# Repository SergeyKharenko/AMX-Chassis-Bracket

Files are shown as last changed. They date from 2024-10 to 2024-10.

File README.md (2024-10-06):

# AMX Chassis Bracket
<div align="center">
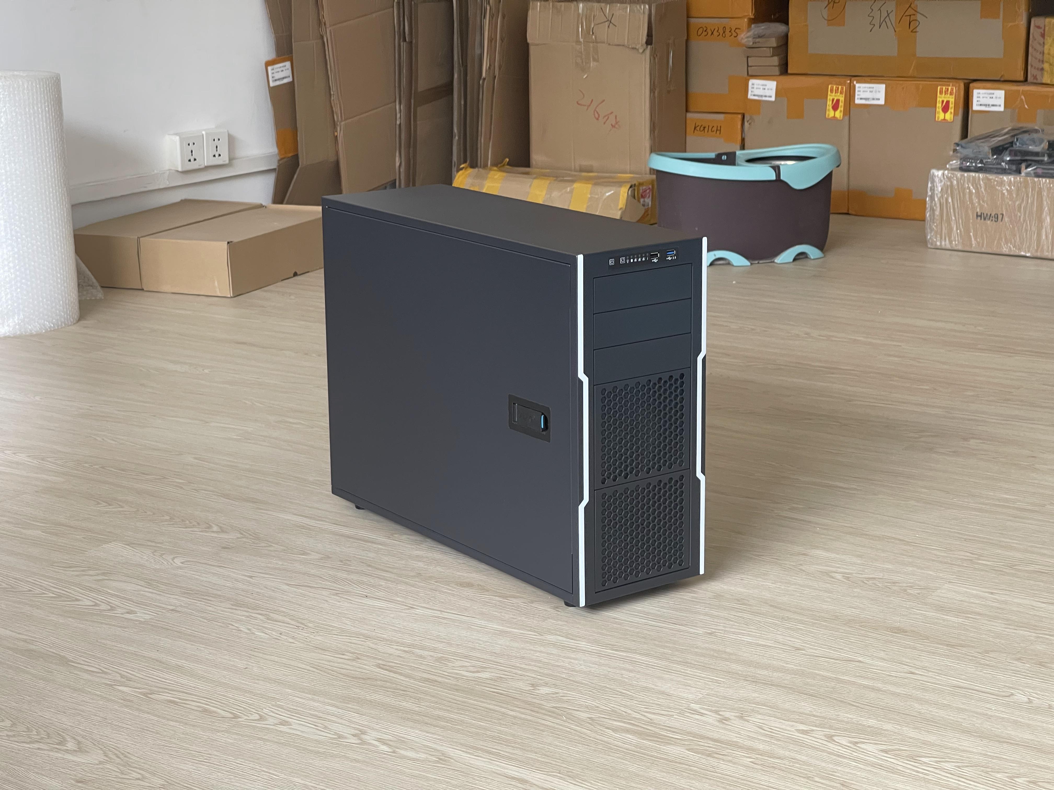
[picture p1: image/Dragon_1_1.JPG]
    
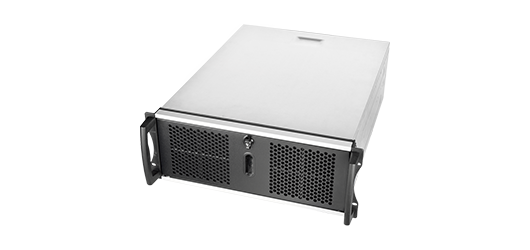
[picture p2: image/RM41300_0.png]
    
</div>
<div align="center">
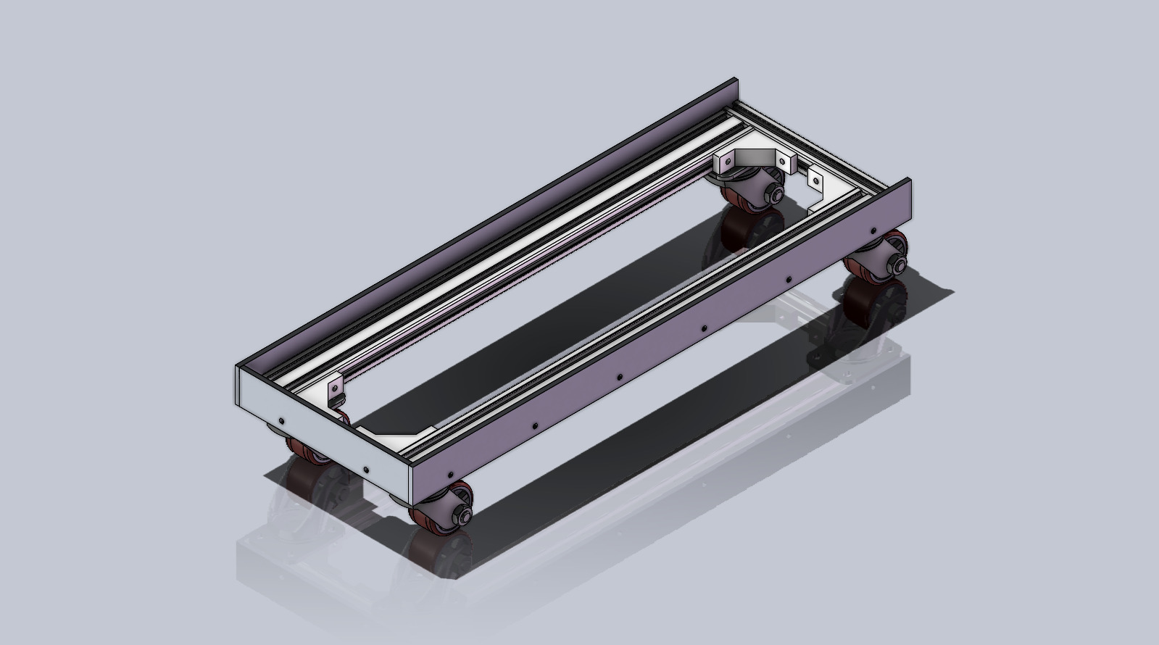
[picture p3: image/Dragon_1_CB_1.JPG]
    
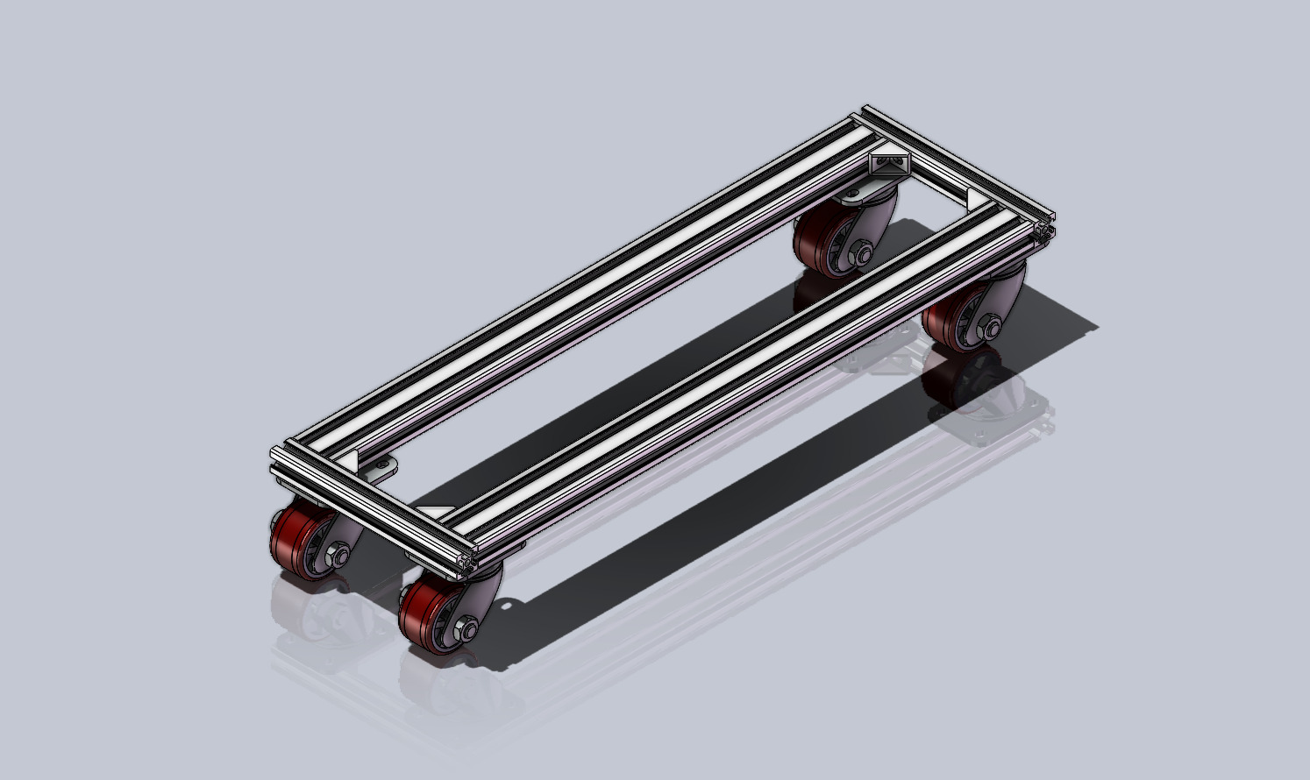
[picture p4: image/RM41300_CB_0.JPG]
    
</div>

## Introduction

This project starts with a PC building in June 2022, I found it is difficult to moving my heavy chassis. Besides, existing chassis brackets on Taobao is either unstable or too expensive(over 200 yuan). Therefore I decided to build the bracket by myself. 

The project aims to provide a fully open source solution of the chassis bracket with advantages below:

- **Fit**  Tailor-made according to the actual size of the chassis to meet your various obsessive-compulsive disorders.
- **Stable**  Aluminum Profile(AP) can support any heavy chassis. Will it shake? IMPOSSIBLE!!! It is much better than any one you can buy online.
- **Cool**  Hollowing out at the bottom is beneficial for heat dissipation of some chassis with vents at the bottom.
- **Quiet** Rubber casters can absorb vibration well.
- **Customizable** All accessories are customizable, you can choose freely according to your needs.

Finished parts(casters) and standard parts(AP) are widely used to reduce costs. However, **it might NOT be so cheap** because the cost of small parts such as screws is also considerable. According to my previous cases, **the total cost range is about 120-180 yuan.** In short, this solution might not be suitable for users who are **extremely cost-sensitive**.

## Compatible Chassis
Currently, I have implemented the following chassis brackets:
- [Dragon 1](chassis/Dragon_1/README.md)
- [RM41300](chassis/RM41300/README.md)

If you have new ideas, welcome to raise an issue~

## Before You Start

### Default Units

**This project uses millimeters(mm) as the unit of length by default!!!** 
Special cases will be specifically pointed out.

### How to use T-Nut
[Bilibili(Chinese)](https://player.bilibili.com/player.html?isOutside=true&aid=917693577&bvid=BV1tu4y1Y7eb&cid=1313380385&p=1),
[Youtube(English)](https://www.youtube.com/watch?v=_kZTA5S2jWY)

### How and Why to use Washer
[Bilibili(Chinese)](https://www.bilibili.com/video/BV1Qz4y1T7m6/?share_source=copy_web&vd_source=c79616b3b42ebfb1c3a4223d9ffdf564),
[Youtube(English)](https://www.youtube.com/watch?v=lbIHMyxHkds)

### Recommended Assembly
<div align="center">
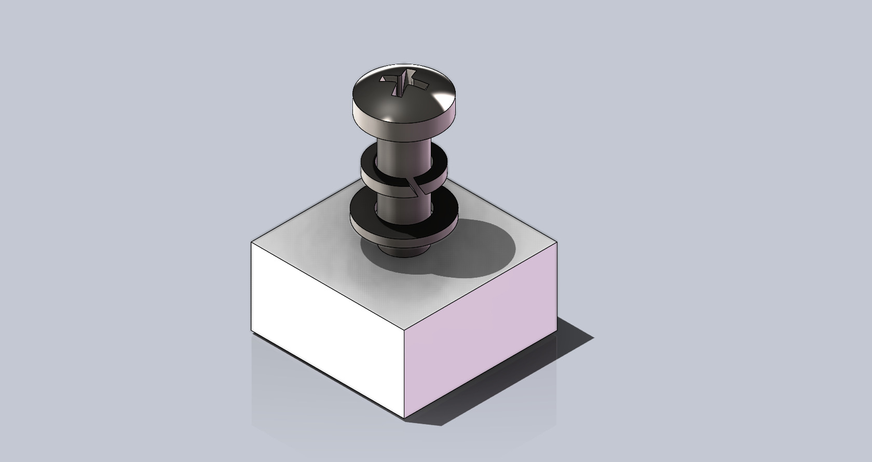
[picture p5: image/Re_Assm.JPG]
    
</div>

From top to bottom in the fig are **screws, spring washers, flat washers, and part to be installed**.

### Standard Part
#### Aluminum Profile
Aluminum profiles are versatile components widely used in various industries, including construction, automotive, and manufacturing. These profiles are typically created through an extrusion process, where heated aluminum alloy is forced through a die to achieve specific shapes and sizes.

T-slot aluminum(TSA) is a type of extruded aluminum profile that features a T-shaped slot running along its length. This design allows for easy and flexible connection of different aluminum profiles using a variety of connectors, fasteners, and accessories. So this project use it as the main support component. 

<div align="center">
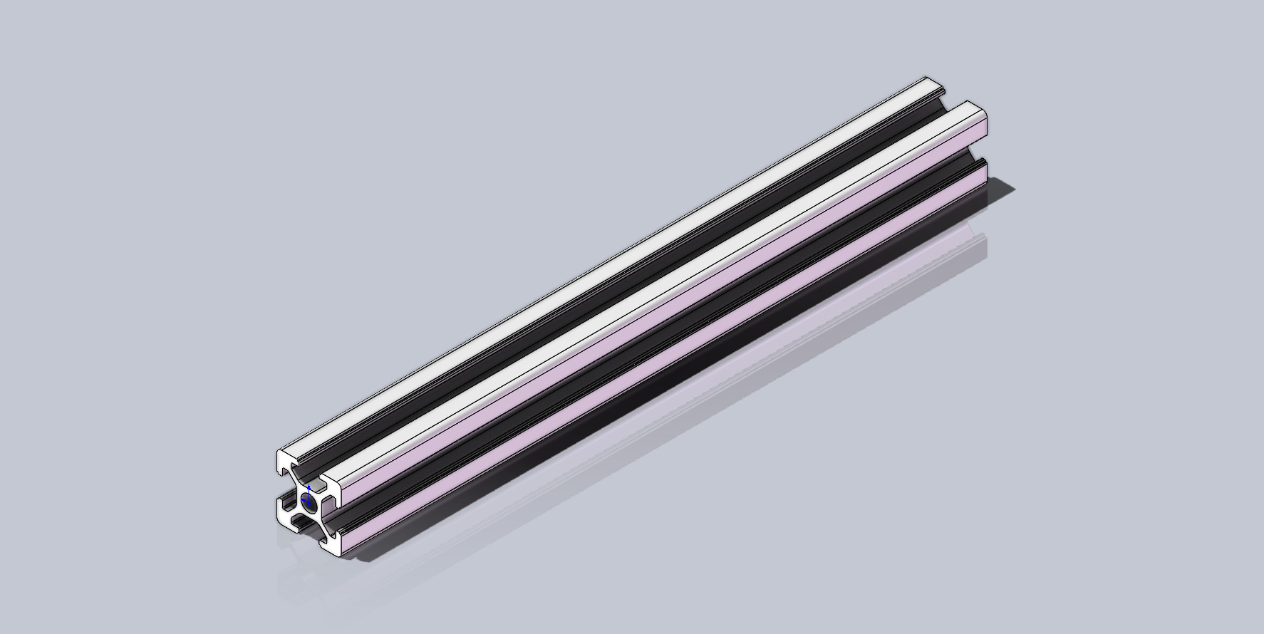
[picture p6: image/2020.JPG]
    
</div>

Model name of the TSA is based on the cross-sectional dimensions. E.g. the cross-sectional dimension of 20 mm in both width and height is named 2020. Common models are 1515, 2020, 2040, 2060, 3030...

**This project mainly uses the Model 2020 and 2040 to get a good balance between cost and stiffness.**

In addition, there are variants of single-sided or even multi-sided closure of TSA:
<div align="center">
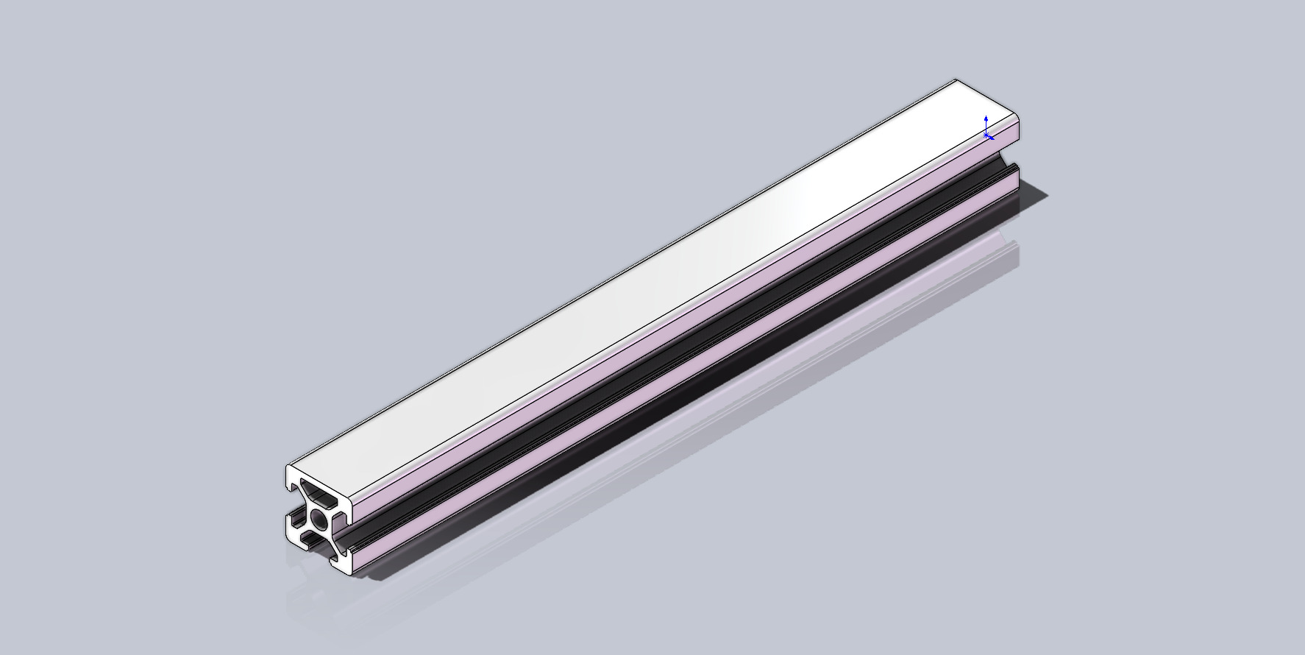
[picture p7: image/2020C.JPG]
    
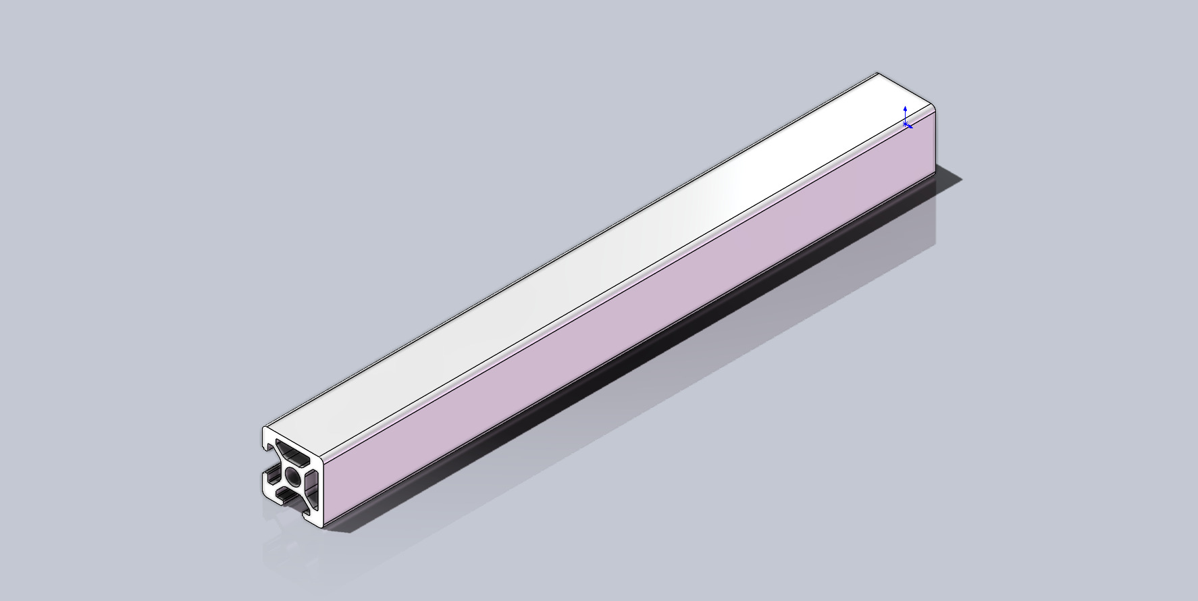
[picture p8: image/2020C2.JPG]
    
</div>

#### Corner Connector

Corner connector is one of the most common fastener used for TSA. It has a variety of sizes, corresponding to different models of TSA.

<div align="center">
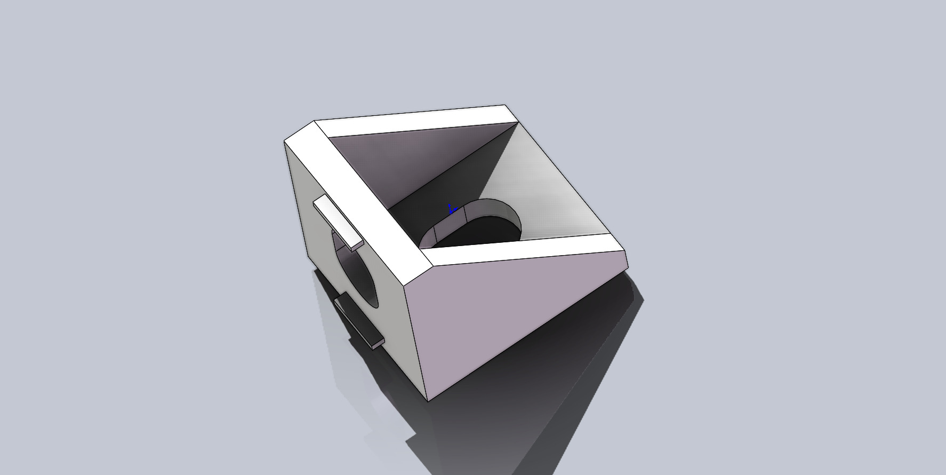
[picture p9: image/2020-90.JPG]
    
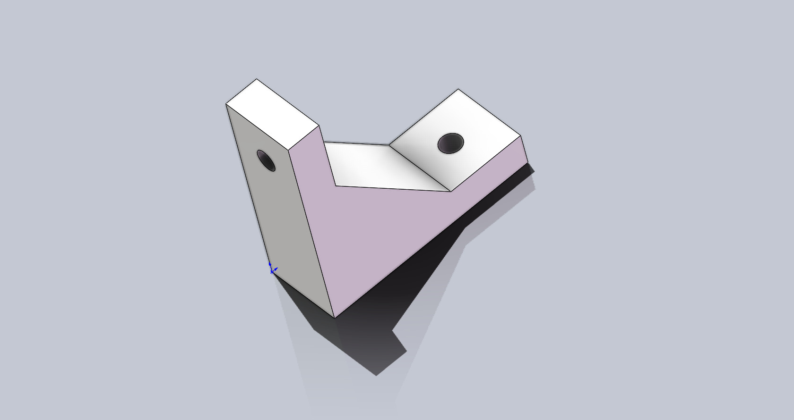
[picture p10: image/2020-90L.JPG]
    
</div>

The left is the standard corner connector. It can be purchased in any store that specializes in TSA.
The right has better structural strength(also a little more expensive). It is provided by the store where I bought. I believe other store also have similar part. The size might not be the same. 

**You can choose flexibly according to the actual situation.**

Fig below is an example of its' usage:
<div align="center">
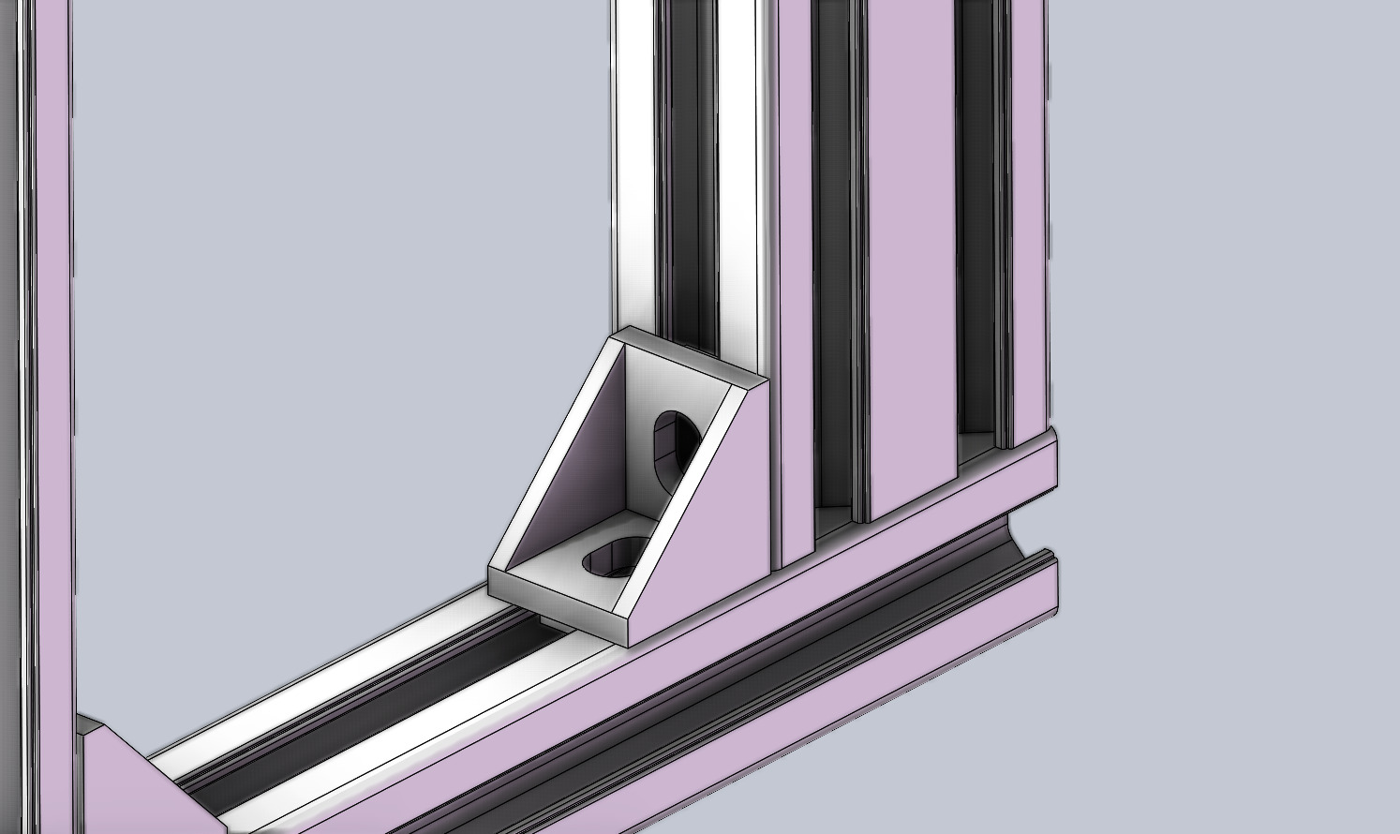
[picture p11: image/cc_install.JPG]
    
</div>

### Caster

The caster is the core to the free movement of the chassis. Reliable castor is equipped with a variety of bearings to support pressure while meeting the need for smooth movement. Of course, this also leads to the fact that this part may be a little expensive (around 20-30 yuan per set).

<div align="center">
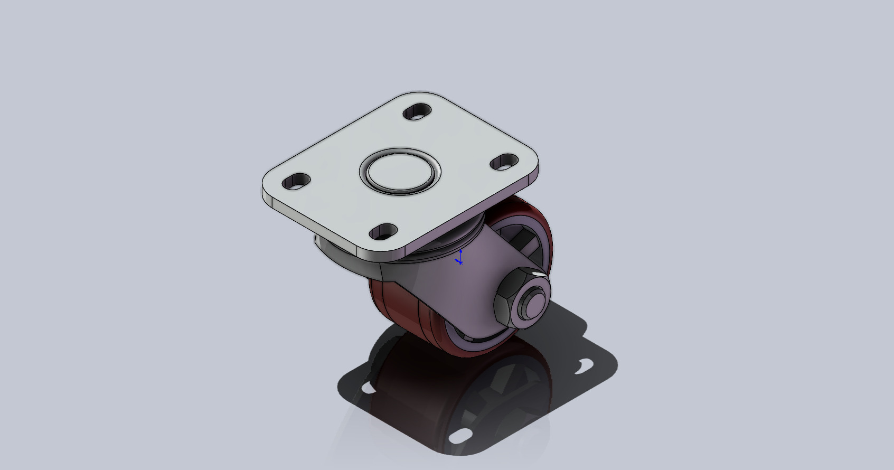
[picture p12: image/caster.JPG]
    
</div>

According to the size of the wheel diameter, the common casters are 1-inch, 1.25-inch, 1.5-inch, 2-inch, etc... 

**It is important to note that casters that are too small have a very limited load capacity, and casters that are too large will cause the center of the chassis gravity to be too high and cause instability**

Based on previous experience, **it is recommended to use casters of 1.5-inch**.

## Design and Review
### Prerequisites
- Dassault Systèmes' SOLIDWORKS 2024 and higer

### Folder Structures
```
|-- AMX Classis Bracket
            |
            |---- chassis Parts and assemblies of brackets for different chassis
            |       |
            |       |---- share Shared parts(corner connector, caster...)
            |       |
            |       |---- Dragon_1 
            |       |
            |       |---- RM41300
            |       :
            |       :
            |       |---- Other Classis
            |
            |---- drawing Machining drawings
            |
            |---- image Images used in README
```

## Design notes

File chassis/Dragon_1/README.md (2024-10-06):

# Dragon 1
<div align="center">
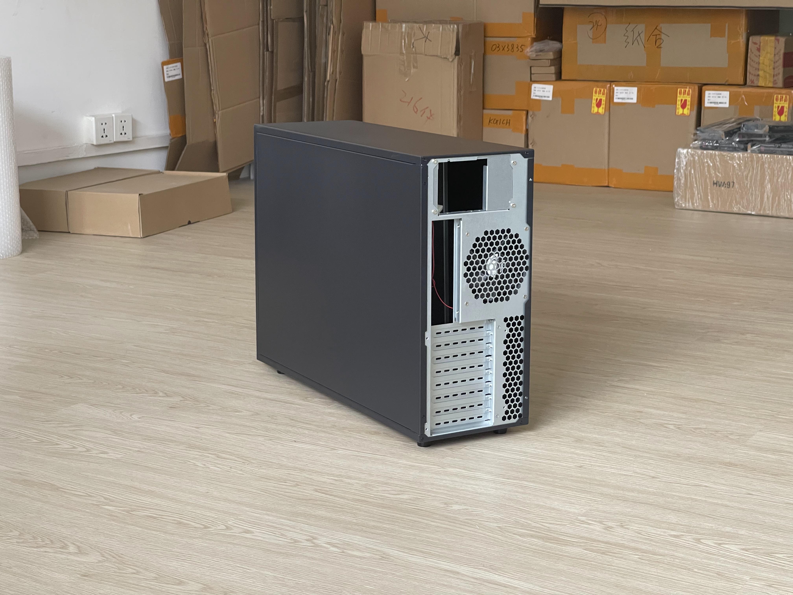
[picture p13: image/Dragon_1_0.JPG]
    
    
</div>
<div align="center">
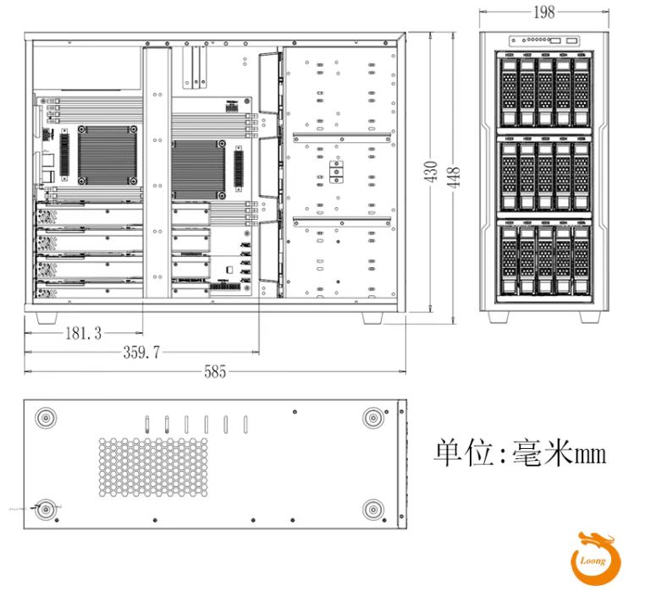
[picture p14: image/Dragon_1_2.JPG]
    
</div>

## Chassis Bracket
<div align="center">
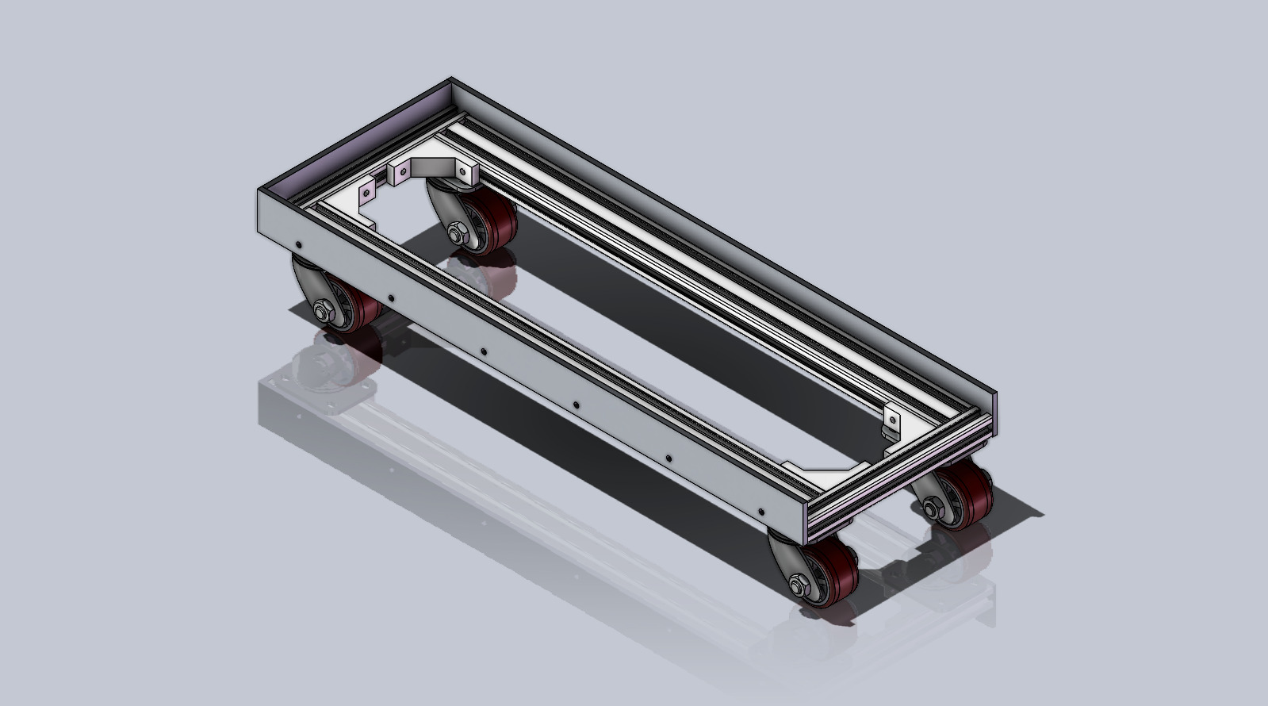
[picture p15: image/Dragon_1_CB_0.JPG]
    
    
</div>

## BOM

| Name | Model | Spec | Drawing | Quantity | Price(yuan) | Note |
|:---:|:---:|:---:|:---:|:---:|:---:|:---:|
| TSA | 2020 | Length: 200 | | 2 | 5.54 |  Recommend single-sided closure |
| | 2040 | Length: 545 | | 2 | 25.51 |  Recommend single-sided closure on 40 side |
| Corner Connector | Compatible to Model 20 TSA | | | 4 | 9.8 | |
| Aluminum Panel | Thick: 5, Width: 40 | Length: 200 | [c0](../../drawing/cover5X40X200.pdf) | 1 | 3.17 | Send drawing to the manufacturer*  |
| | | Length: 590 | [c1](../../drawing/cover5X40X590.pdf) | 2 | 18.71 | Send drawing to the manufacturer |
| Caster | 1.5-inch | | | 1 set | 30 |  1 set include 4 casters |
| Washer | Spring Washer | M5 | | 20 | 6.8 | |
| | Flat Washer | 5\*12\*1.0  | | 20 | 6 | |
| Hexagon Socket Screw | Round Head | M5*8 | | 20 | 5 | |
| | Flat Head Chamfered | M5*10 | | 14 | 5.85 |  For fastening side panels |
| T-Nut | Compatible to Model 20 TSA | M5 | | 34 | 3.4 | |
| Rubber Feet** | D: 40, Thick: 8 | | | 4 | 8 | |
| Miscellaneous*** | | | | | 35 | |
| Total | | | | | 168 | |

*note: Holes need to be drilled, so the drawing must be sent to the manufacturer!

**note: As shown in the fig below:

<div align="center">
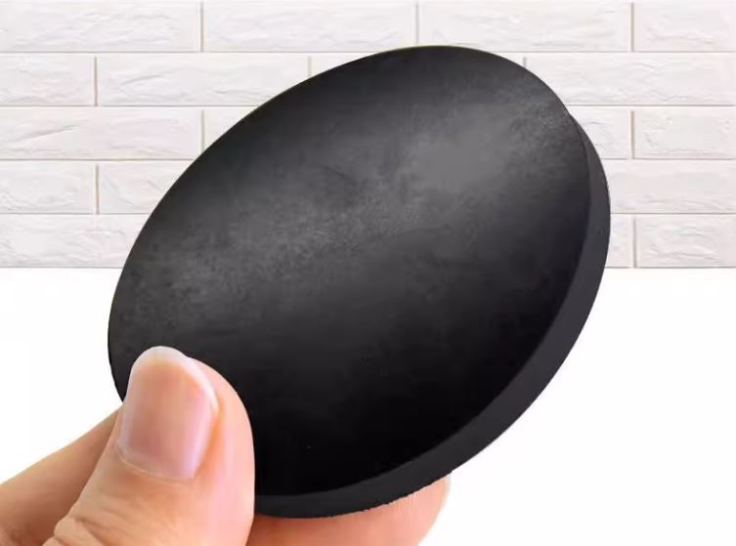
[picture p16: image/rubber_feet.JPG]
    
</div>

***note: Include machining, freight, etc.

## Prerequisites

- Hexagonal Wrench
- Small File
- Phillips Screwdriver

## How to Install

<div align="center">
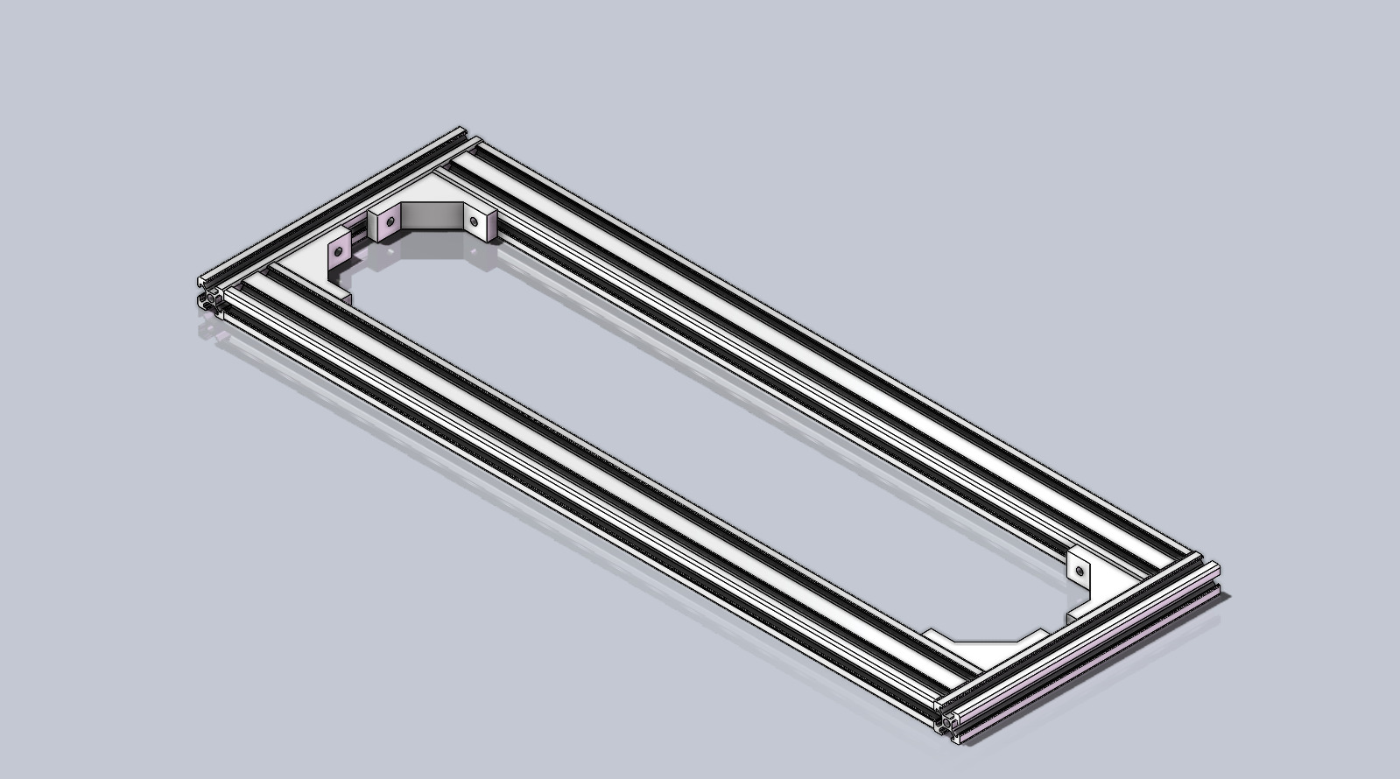
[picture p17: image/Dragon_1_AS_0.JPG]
    
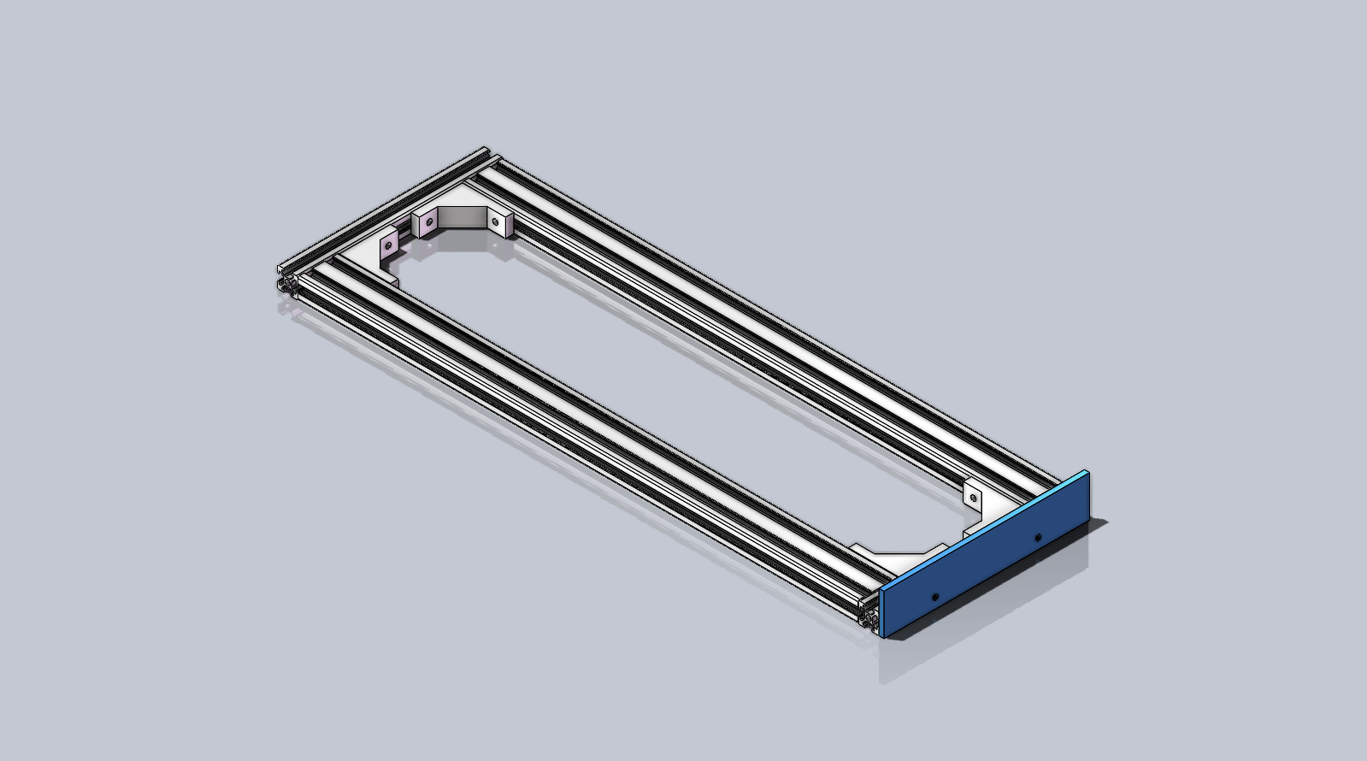
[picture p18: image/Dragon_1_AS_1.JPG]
    
</div>
<div align="center">
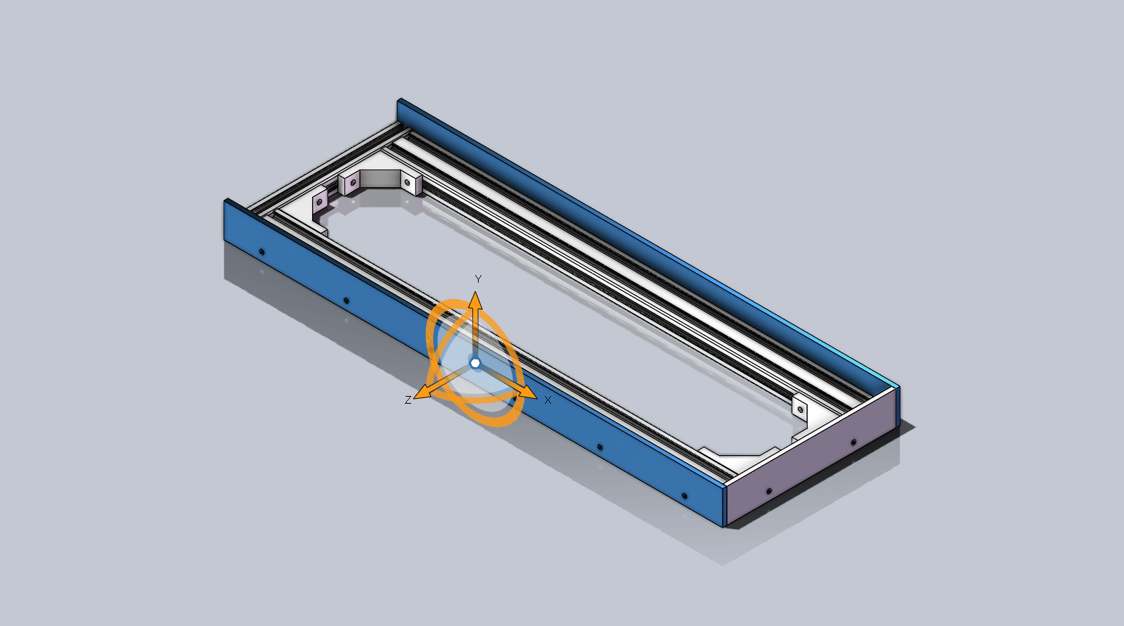
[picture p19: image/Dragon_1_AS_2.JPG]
    
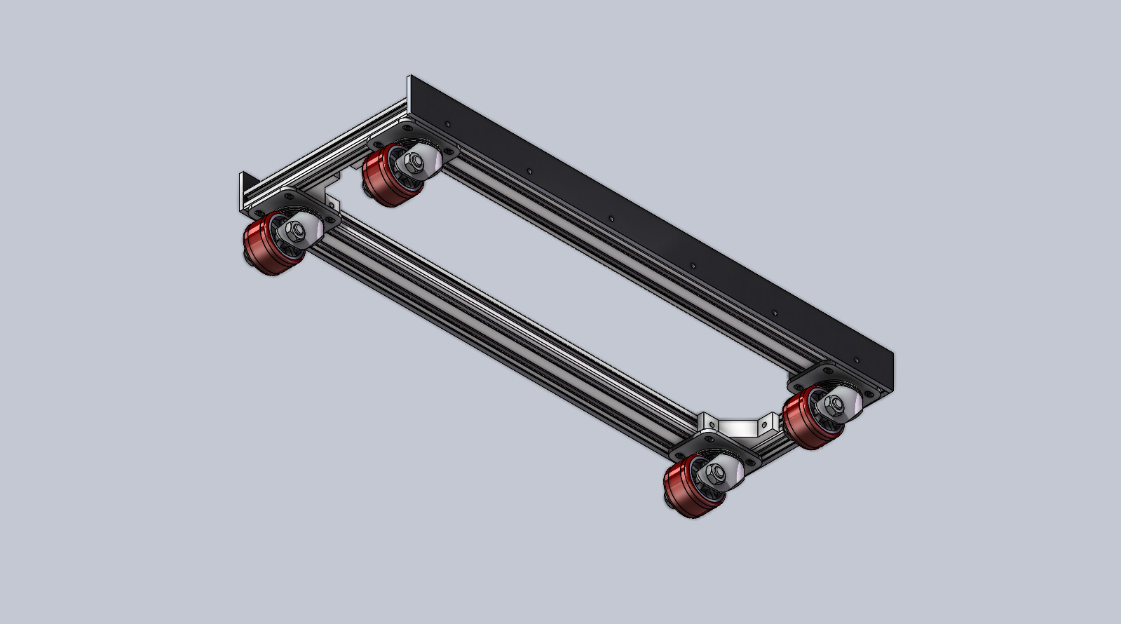
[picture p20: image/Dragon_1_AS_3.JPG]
    
</div>
<div align="center">
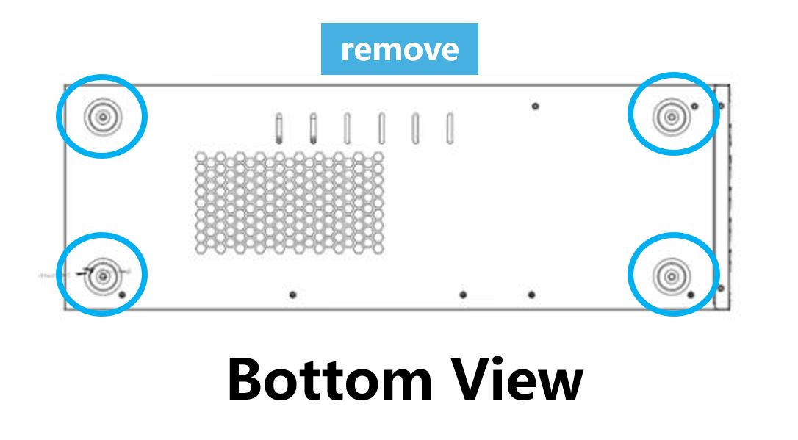
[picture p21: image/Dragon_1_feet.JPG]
    
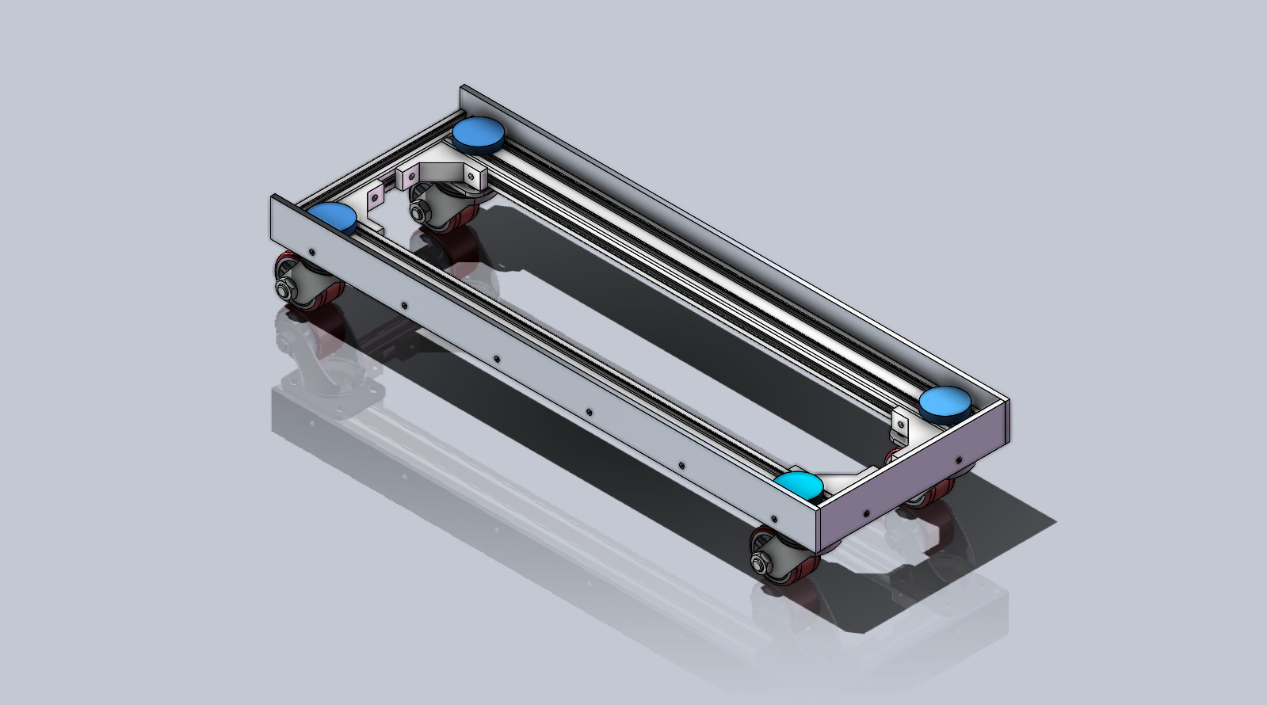
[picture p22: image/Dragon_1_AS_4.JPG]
    
</div>

1. Connecting TSA using corner connector. Pay attention to the assembly order! It is recommended to assemble on a flat surface (such as the ground)
2. Install the rear side panel*.
3. Install the left and right side panels. They can wrap the rear side panel.
4. Install casters.
5. Remove the original feet installed under the chassis.
6. Place the rubber feet on the bracket.
7. Place the chassis on the bracket.

*note: When installing the side panels, washers can be omitted for aesthetic reasons, so that the screw heads can fit perfectly with the side panels.

## Caution

The cut edges of the side panels and cornet connector may be sharp, so it is recommended to use a file for chamfering.

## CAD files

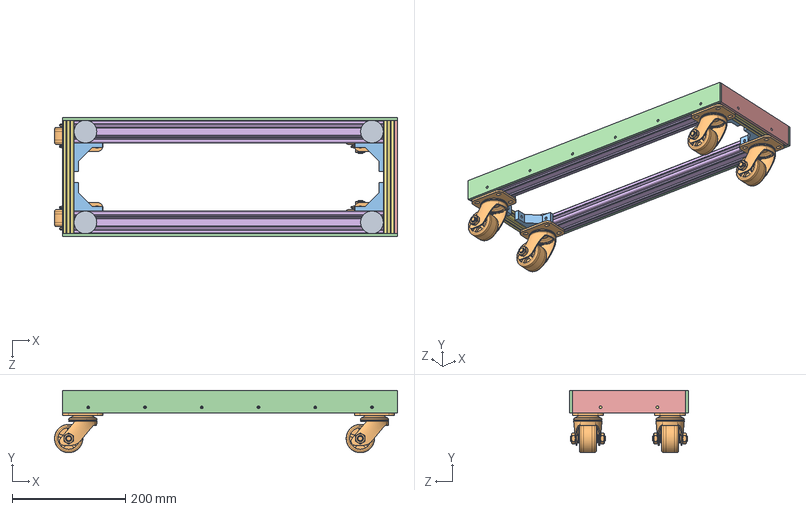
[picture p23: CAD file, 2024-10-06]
chassis/Dragon_1/Dragon_1.SLDASM
604.5 x 110.0 x 210.0 mm
2020X200 x 2
2040X545 x 2
cover5X40X200
cover5X40X590 x 2
2020-90L x 4
caster x 4
rubber_feet_8x40 x 4

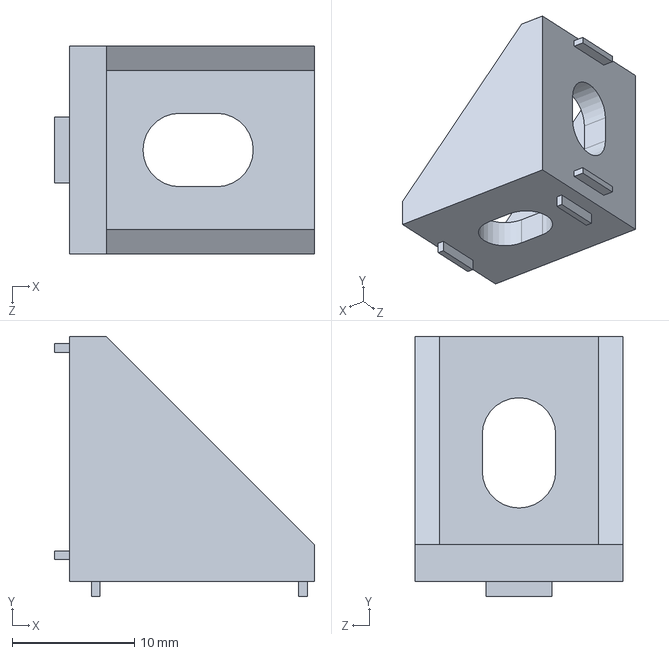
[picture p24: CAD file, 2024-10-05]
chassis/share/2020-90.SLDPRT
21.2 x 21.2 x 17.0 mm

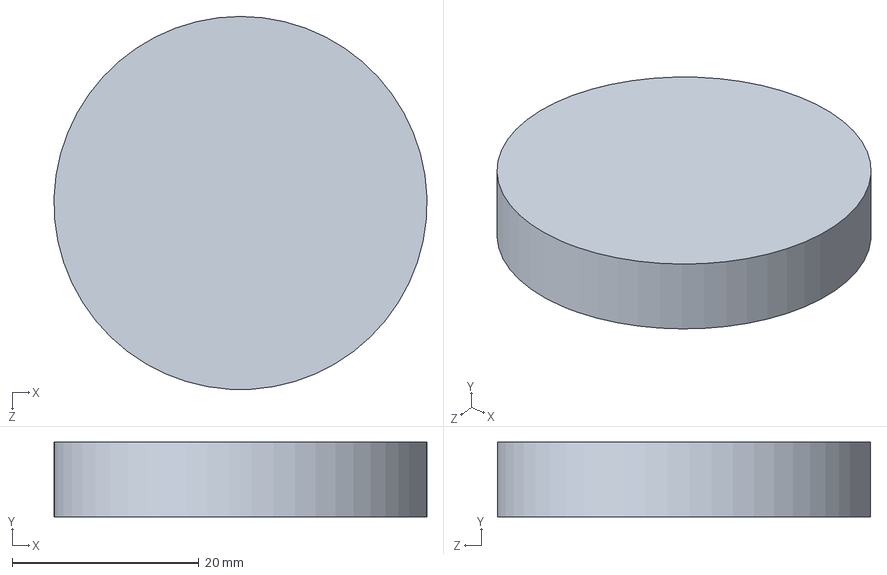
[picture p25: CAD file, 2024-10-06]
chassis/Dragon_1/rubber_feet_8x40.SLDPRT
40.0 x 8.00 x 40.0 mm

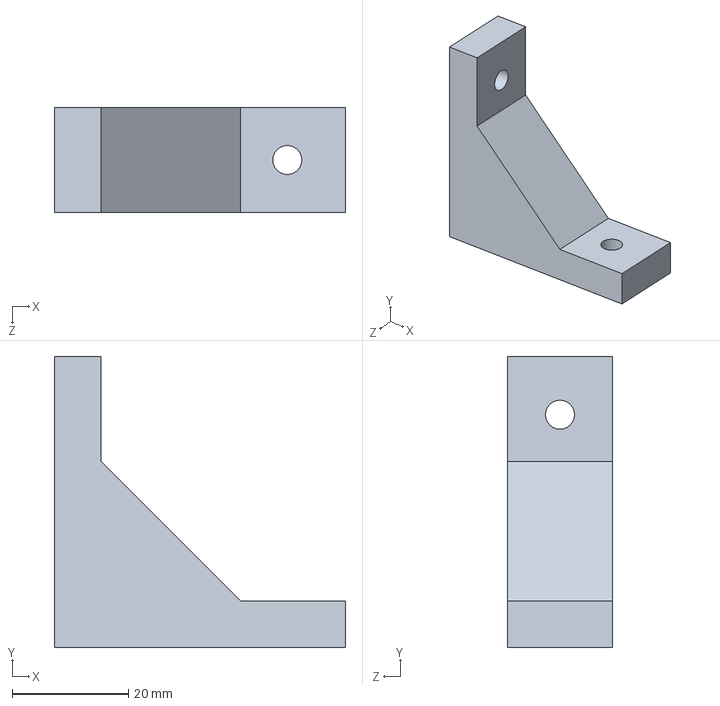
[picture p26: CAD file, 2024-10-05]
chassis/share/2020-90L.SLDPRT
50.0 x 50.0 x 18.0 mm

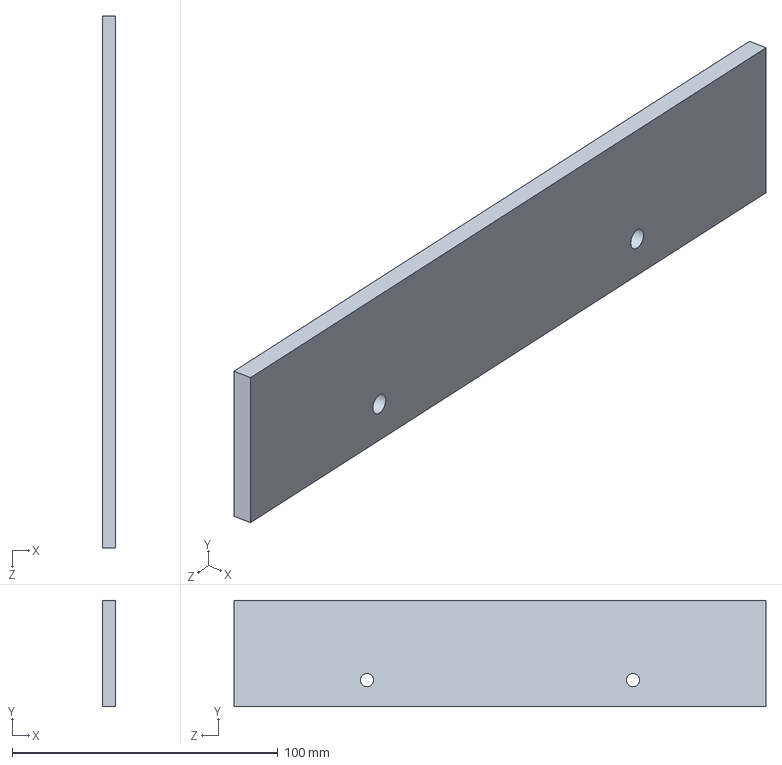
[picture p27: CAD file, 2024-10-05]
chassis/Dragon_1/cover5X40X200.SLDPRT
5.00 x 40.0 x 200.0 mm

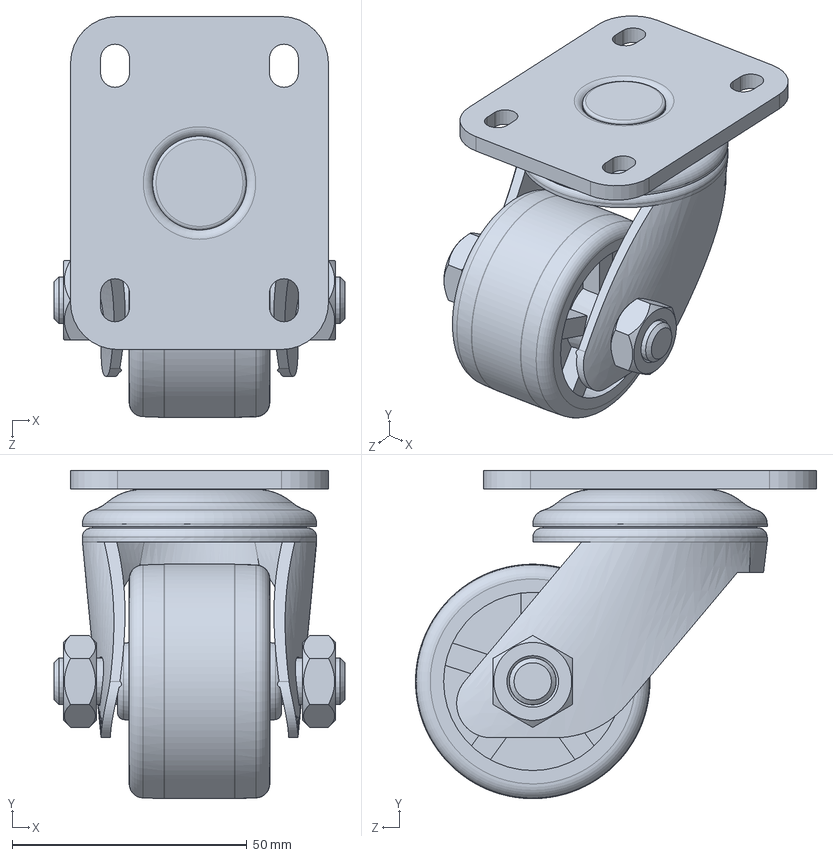
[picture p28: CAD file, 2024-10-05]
chassis/share/caster.SLDPRT
62.0 x 70.0 x 85.5 mm

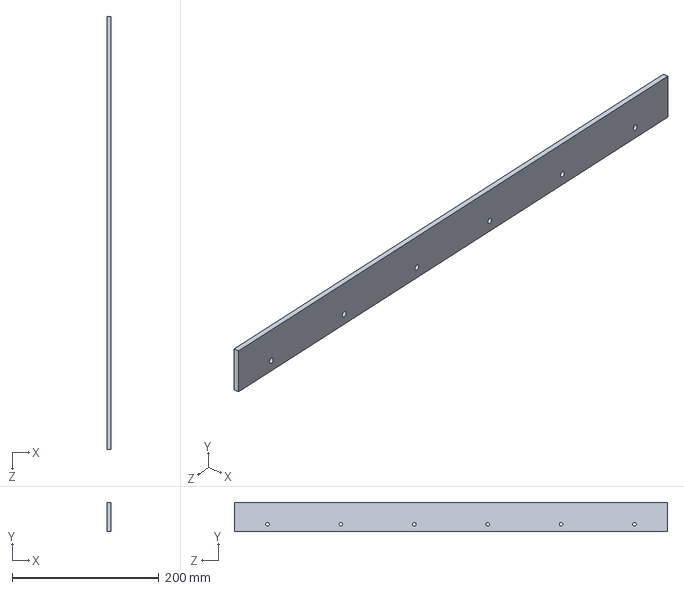
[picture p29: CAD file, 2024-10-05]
chassis/Dragon_1/cover5X40X590.SLDPRT
5.00 x 40.0 x 590.0 mm

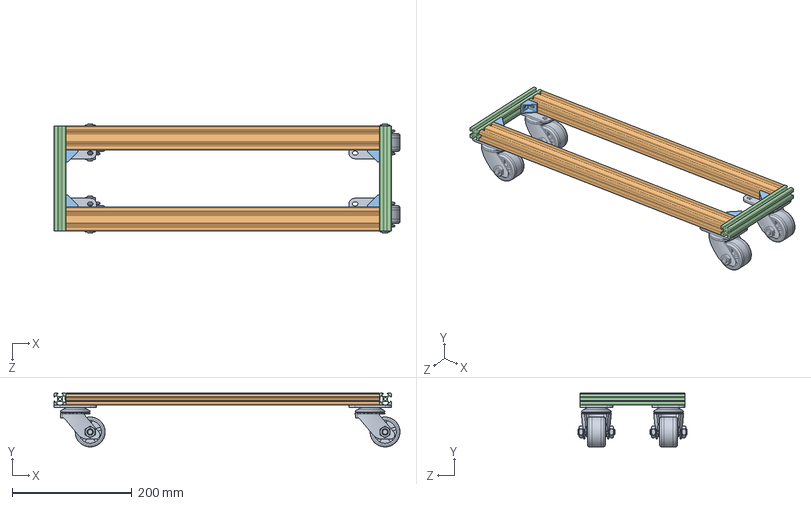
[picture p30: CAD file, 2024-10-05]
chassis/RM41300/RM41300.SLDASM
578.5 x 90.0 x 183.0 mm
2020X176 x 2
2040X524 x 2
caster x 4

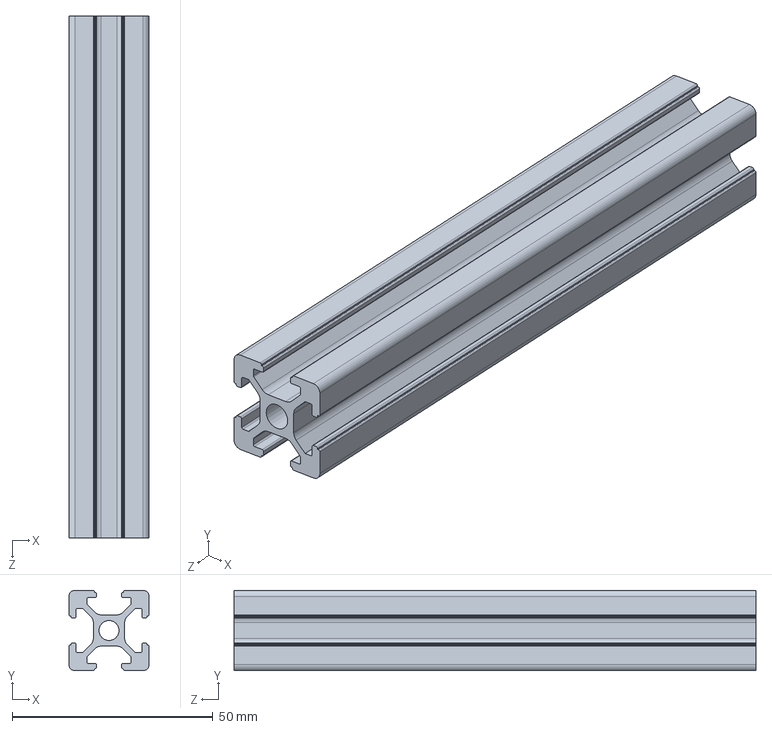
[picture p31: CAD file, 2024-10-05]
chassis/RM41300/2020X130.SLDPRT
20.0 x 20.0 x 130.0 mm

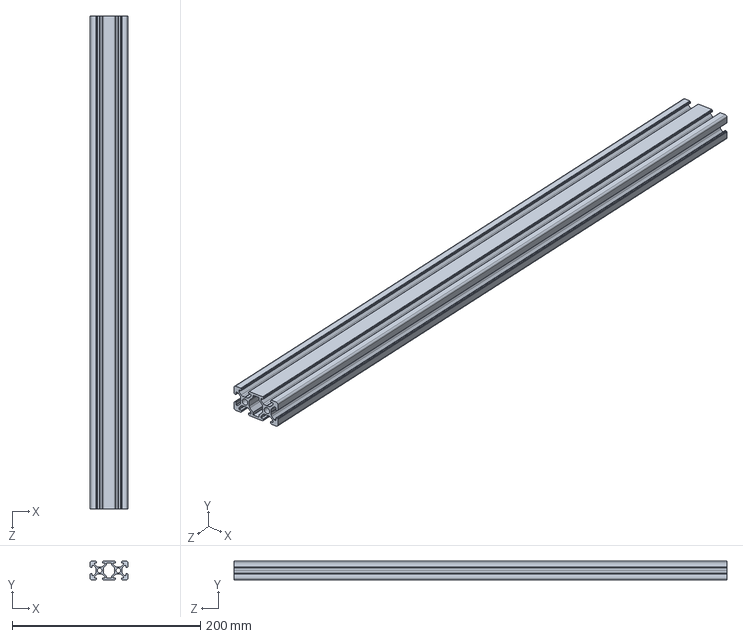
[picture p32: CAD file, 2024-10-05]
chassis/RM41300/2040X524.SLDPRT
40.0 x 20.0 x 524.0 mm

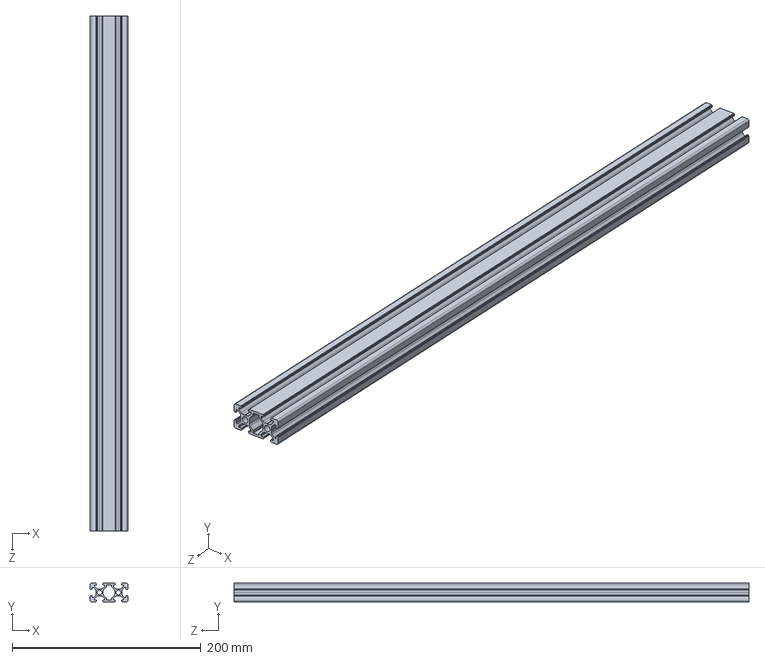
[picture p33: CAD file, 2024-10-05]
chassis/Dragon_1/2040X545.SLDPRT
40.0 x 20.0 x 545.0 mm

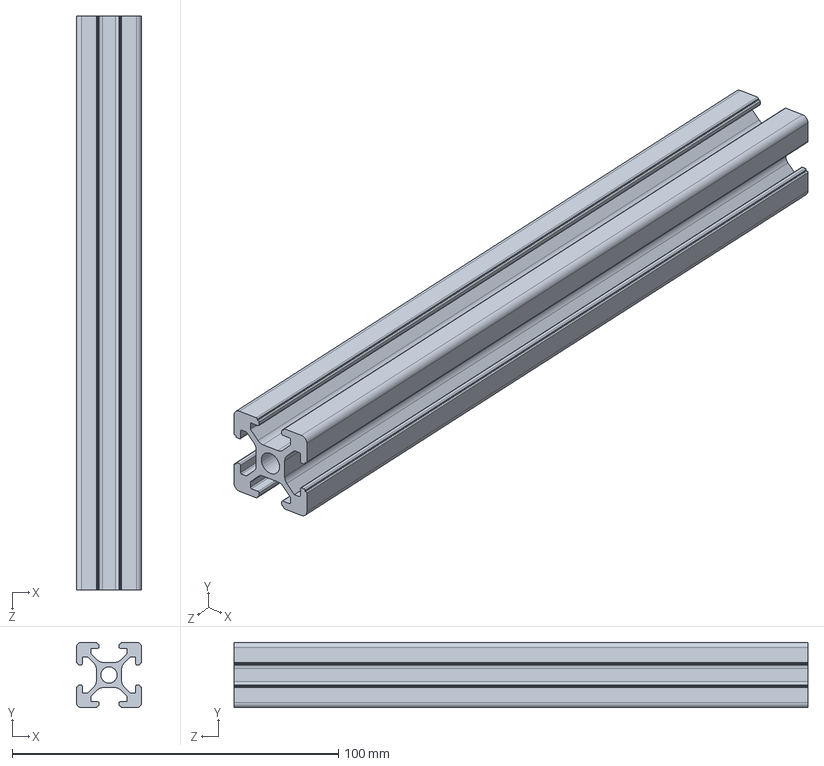
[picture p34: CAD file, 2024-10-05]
chassis/RM41300/2020X176.SLDPRT
20.0 x 20.0 x 176.0 mm

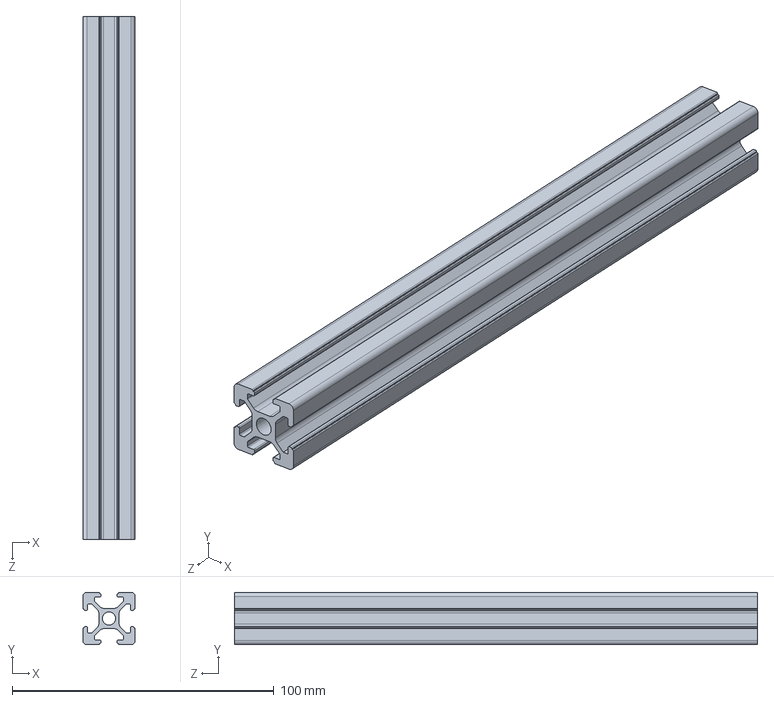
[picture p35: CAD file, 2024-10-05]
chassis/Dragon_1/2020X200.SLDPRT
20.0 x 20.0 x 200.0 mm

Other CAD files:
drawing/cover5X40X200.SLDDRW
drawing/cover5X40X590.SLDDRW

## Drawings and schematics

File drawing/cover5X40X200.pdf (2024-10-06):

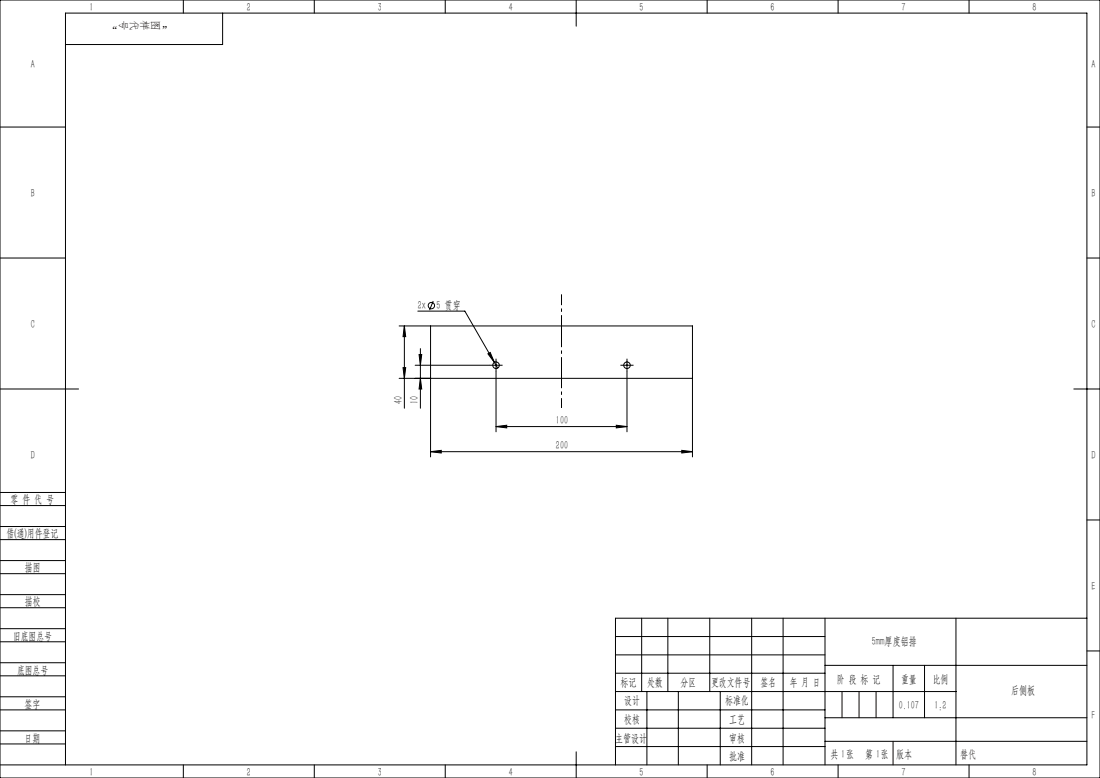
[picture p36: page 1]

5mm厚度铝排

阶 段 标 记 | 重量 | 比例 | 后侧板

标记 | 处数 | 分区 | 更改文件号 | 签名 | 年 月 日
设计 | | | 标准化 | | | 0.107 | 1:2
校核 | | | 工艺
主管设计 | | | 审核

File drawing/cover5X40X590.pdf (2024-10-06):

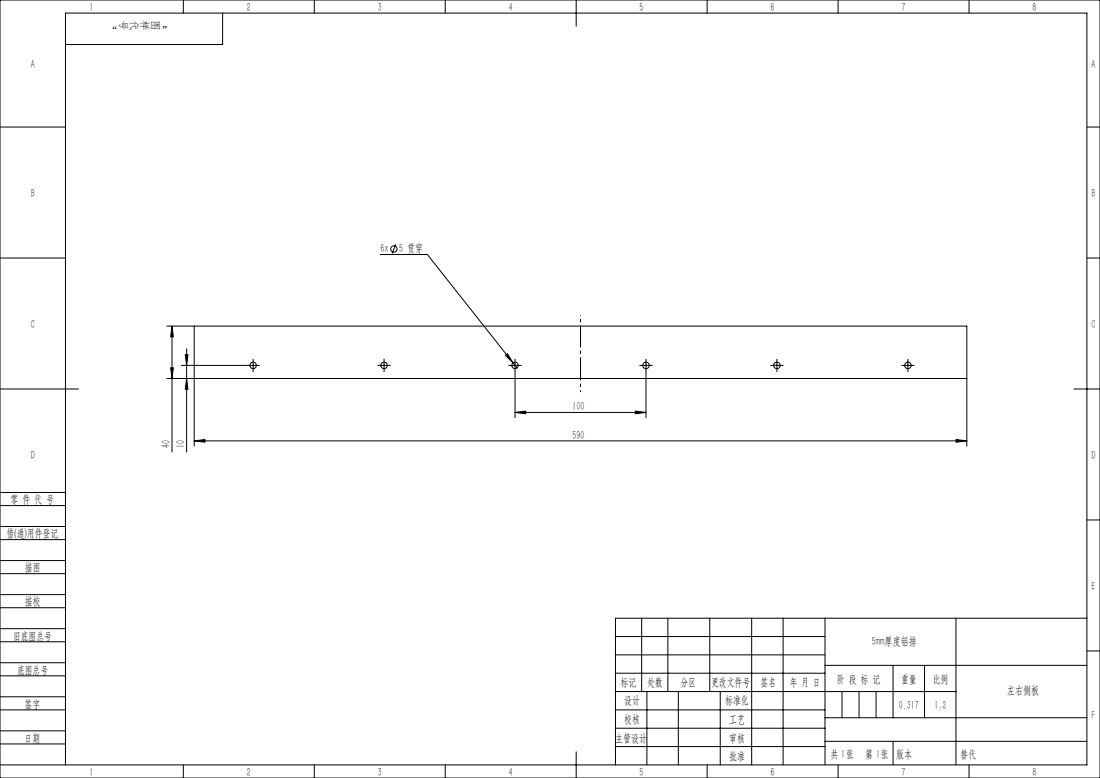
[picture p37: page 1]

5mm厚度铝排

阶 段 标 记 | 重量 | 比例 | 左右侧板

标记 | 处数 | 分区 | 更改文件号 | 签名 | 年 月 日
设计 | | | 标准化 | | | 0.317 | 1:2
校核 | | | 工艺
主管设计 | | | 审核
